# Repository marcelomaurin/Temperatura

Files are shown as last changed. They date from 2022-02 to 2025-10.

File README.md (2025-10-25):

# Projeto Temperatura – Documentação Aprimorada

## Visão Geral

O Projeto Temperatura é uma solução integrada para o controle e monitoramento contínuo de temperatura e umidade em ambientes críticos, como farmácias e geladeiras de medicamentos. O sistema opera 24/7, registrando dados em tempo real e gerando relatórios detalhados com valores atuais, máximos e mínimos, garantindo a segurança e preservação de produtos sensíveis.

## Finalidade

- Monitorar constantemente temperatura e umidade ambiental;
- Assegurar a qualidade e segurança de produtos sensíveis, especialmente medicamentos;
- Gerar relatórios analíticos para acompanhamento e controle eficaz.

## Vantagens

- Operação ininterrupta, 24 horas por dia, 7 dias por semana;
- Relatórios precisos com dados atuais, máximos e mínimos de temperatura e umidade;
- Sistema open source para flexibilidade e personalização;
- Compatível com três tipos de equipamentos de aquisição de dados.

## Equipamentos Suportados

1. **USB Serial (Arduino Nano)**: Comunicação via porta serial USB, ideal para instalações locais simples.  
2. **Ethernet (Arduino Mega com Ethernet Shield)**: Comunicação via rede cabeada, adequado para ambientes com infraestrutura Ethernet.  
3. **ESP8266 (Wi-Fi)**: Conexão sem fio via módulo Wi-Fi, oferecendo maior flexibilidade na instalação.

## Estrutura do Projeto

- **hardware/**: Firmwares para Arduino Nano, Mega com Ethernet Shield e ESP8266, manuais e modelos 3D (STL/SLDPRT) dos dispositivos e protetores.
- **software/**: Código-fonte da aplicação principal em Pascal/Delphi, banco de dados SQLite, instaladores para Windows e Linux, bibliotecas e ferramentas auxiliares (SQLiteStudio).
- **docs/**: Documentação técnica, manuais em PDF.
- **imgs/**: Imagens e capturas de tela ilustrativas de hardware e software.
- **.git/**: Configurações e arquivos para controle de versão com Git.

## Instalação e Configuração

1. Instale o equipamento de medição adequado ao ambiente.  
2. Configure o software informando o tipo do equipamento e parâmetros de comunicação.  
3. Execute a aplicação para iniciar o monitoramento contínuo.

## Interface do Sistema – Exemplos de Telas

### MSTemp01 – Visões dos Sensores  

| Visão Superior | Visão Traseira |
|---|---|
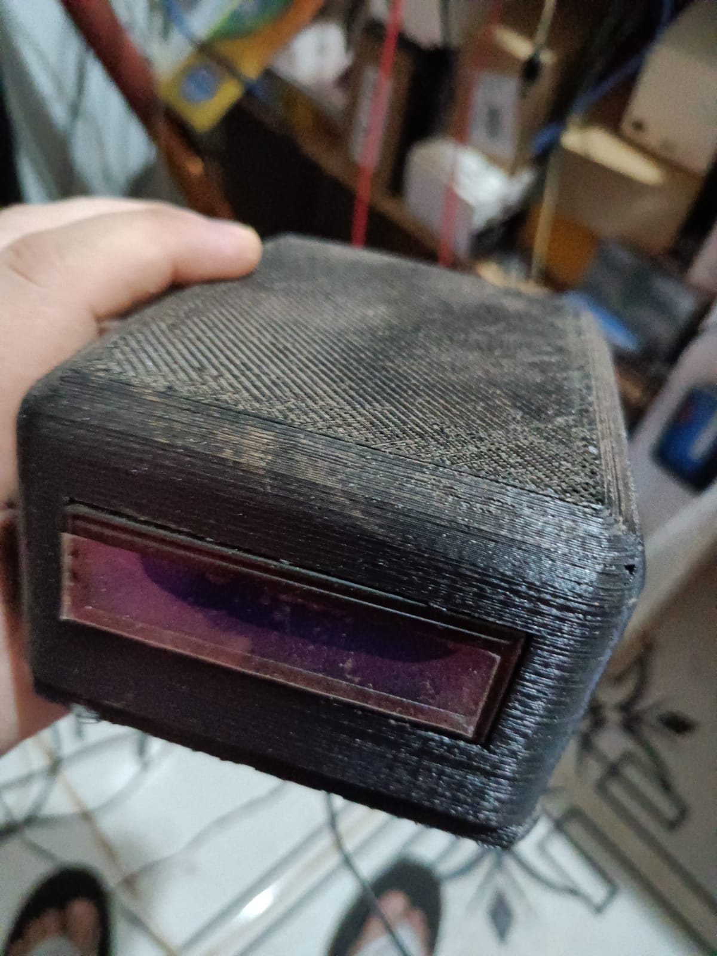
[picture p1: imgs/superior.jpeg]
Visão Superior
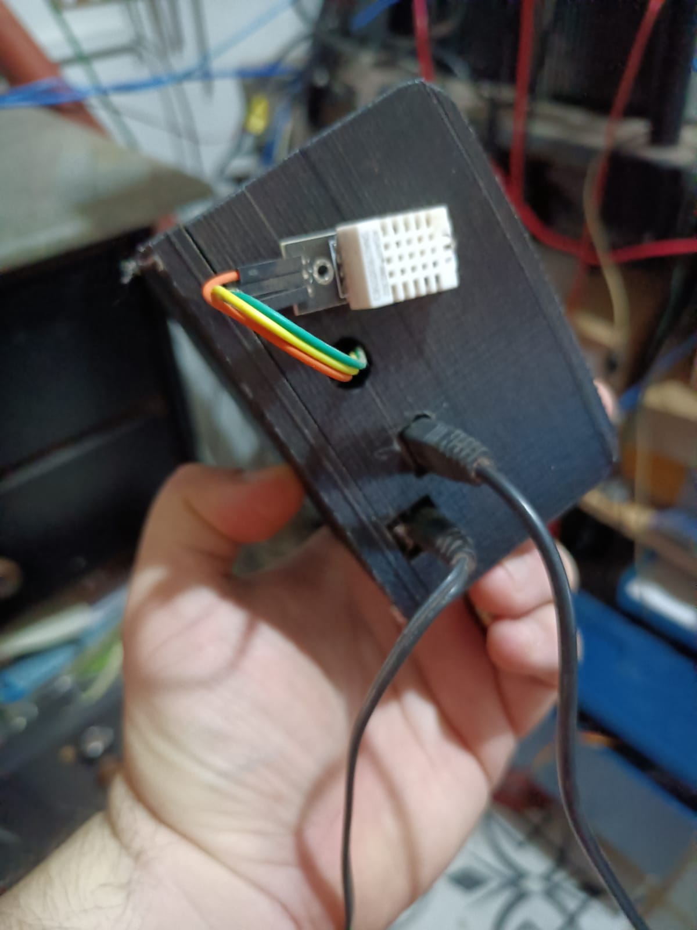
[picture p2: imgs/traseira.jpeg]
Visão Traseira
|  |  |

## Imagens do projeto

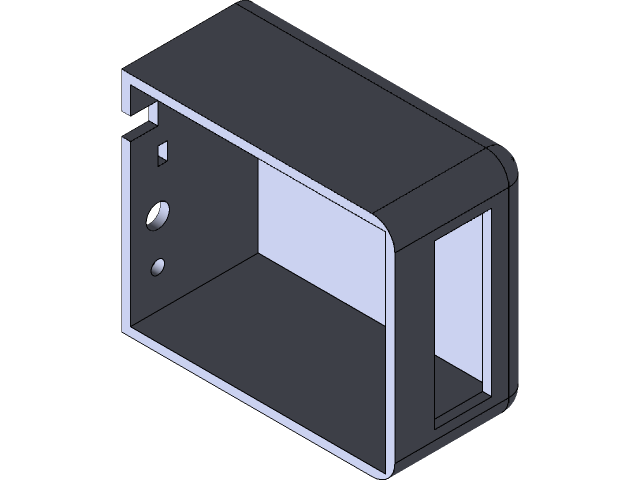
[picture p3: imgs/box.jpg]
|  |
|---------------------|
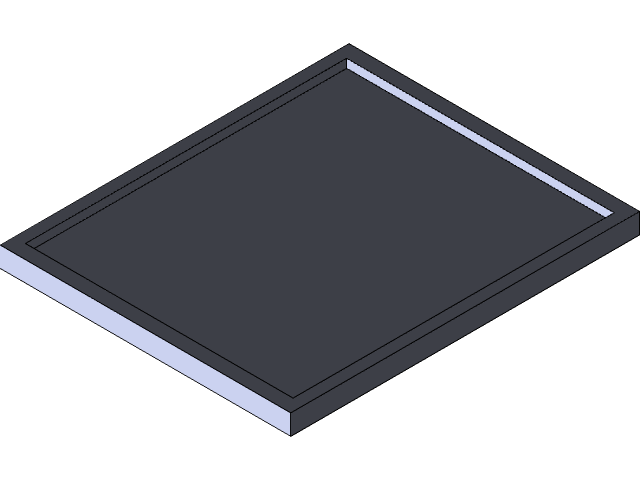
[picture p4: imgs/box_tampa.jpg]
|  |
|  |
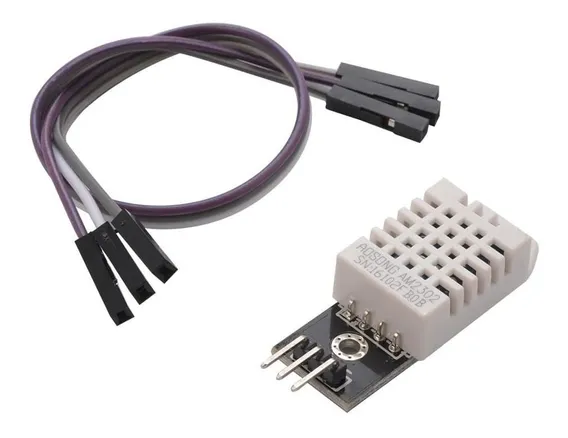
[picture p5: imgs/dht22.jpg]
|  |
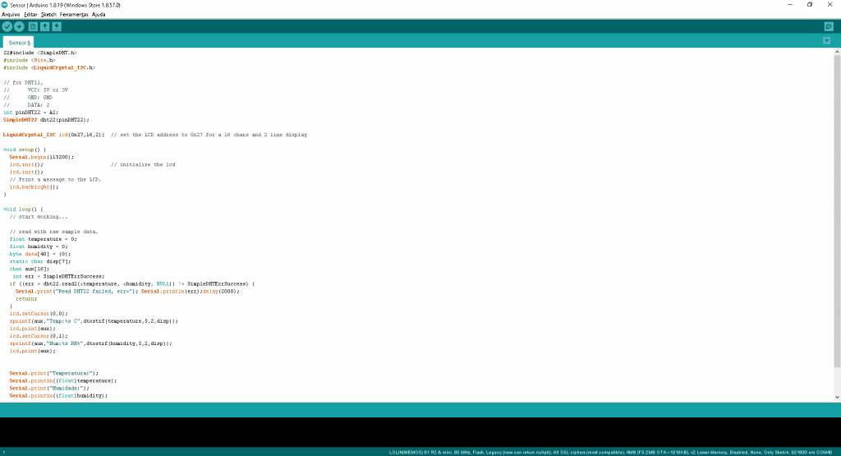
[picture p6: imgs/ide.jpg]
|  |
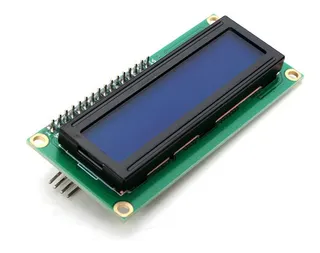
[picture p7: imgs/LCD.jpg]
|  |
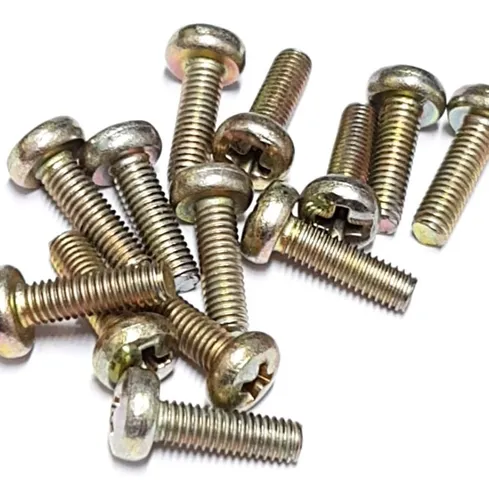
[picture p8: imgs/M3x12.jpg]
|  |
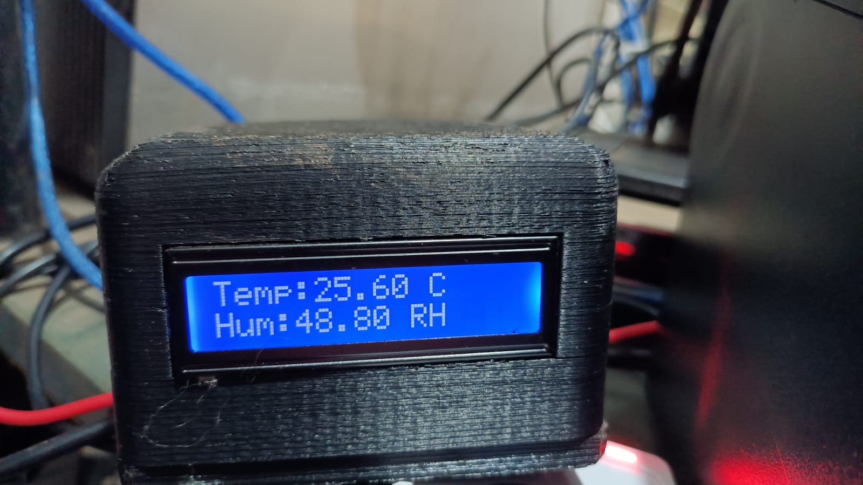
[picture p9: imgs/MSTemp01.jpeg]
|  |
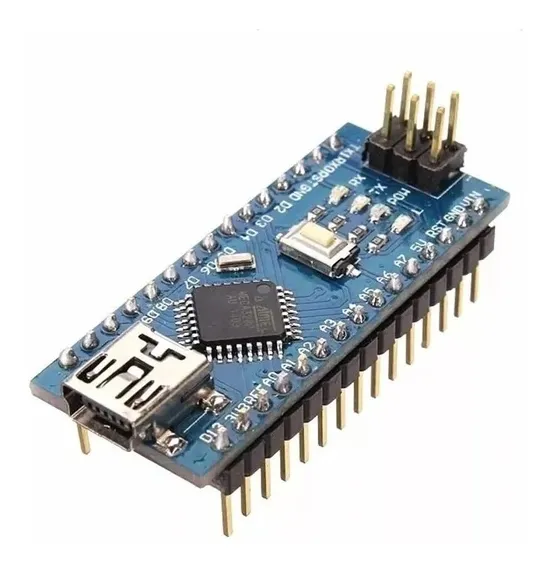
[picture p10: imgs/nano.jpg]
|  |
| setup_protetor_100.exe |
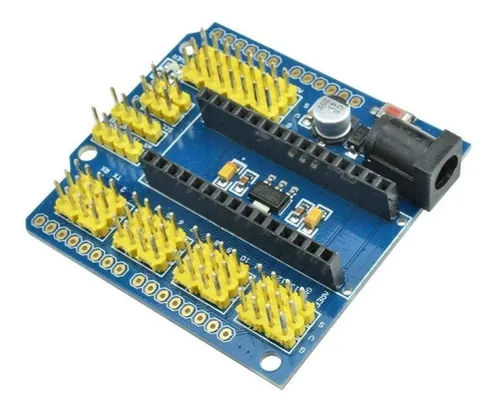
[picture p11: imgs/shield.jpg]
|  |
|  |
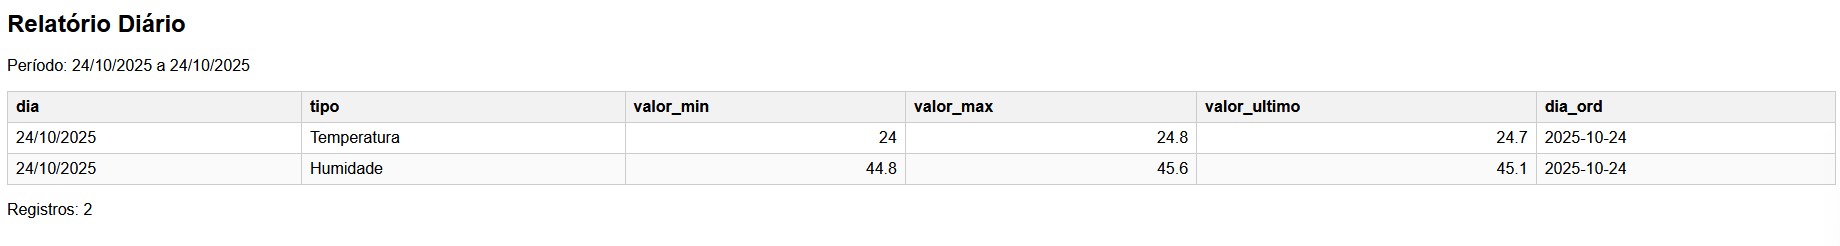
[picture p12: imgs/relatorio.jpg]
|  |
|  |
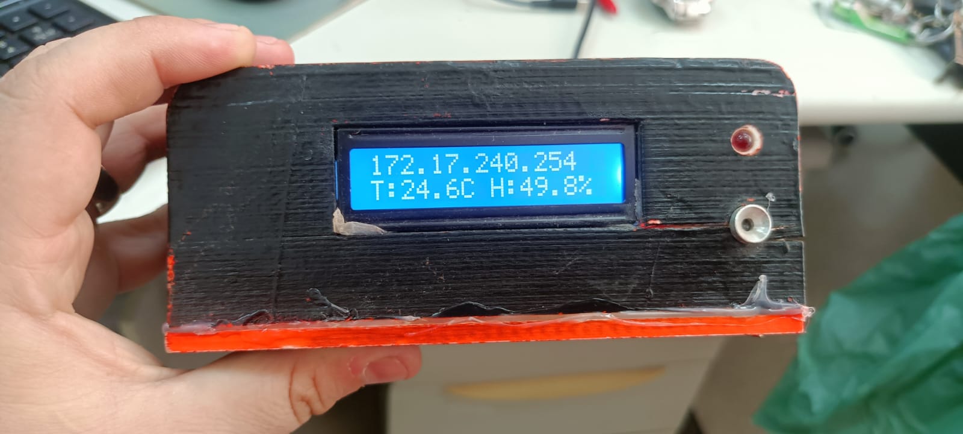
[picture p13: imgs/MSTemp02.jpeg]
|  |
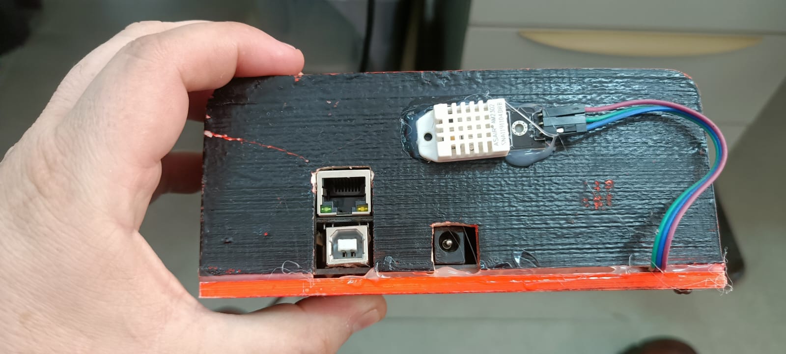
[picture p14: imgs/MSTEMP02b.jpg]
|  |
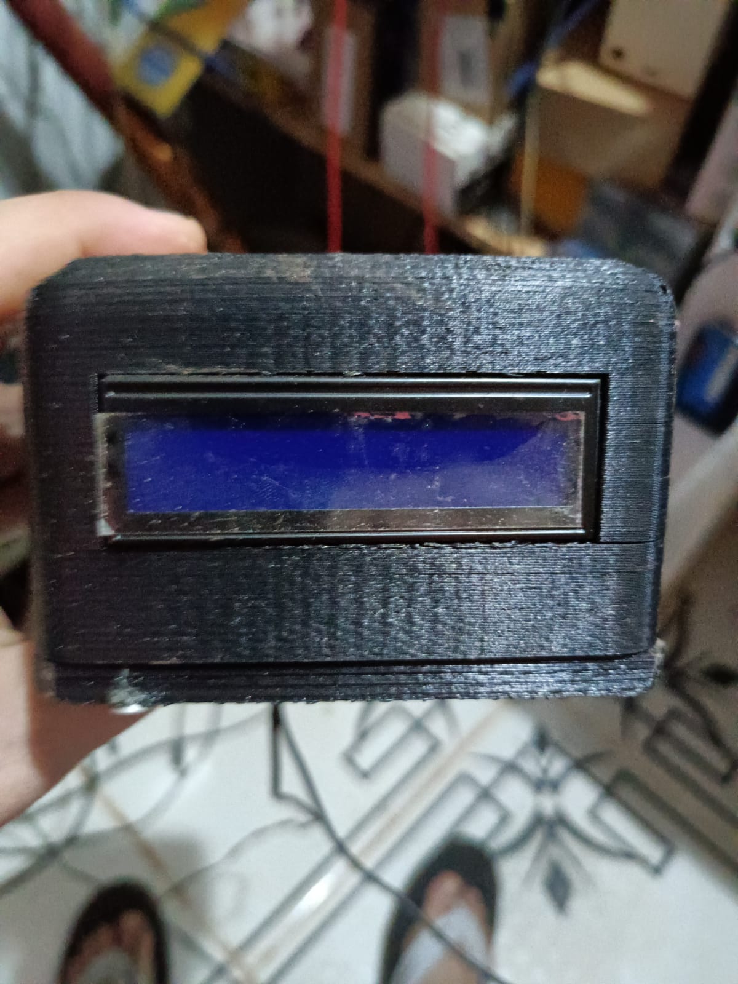
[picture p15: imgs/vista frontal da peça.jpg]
vista frontal da peça.jpg
|  |

## Telas do Instalador

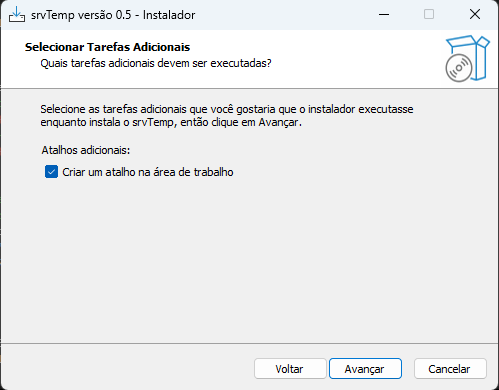
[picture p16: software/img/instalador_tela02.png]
Instalador 2
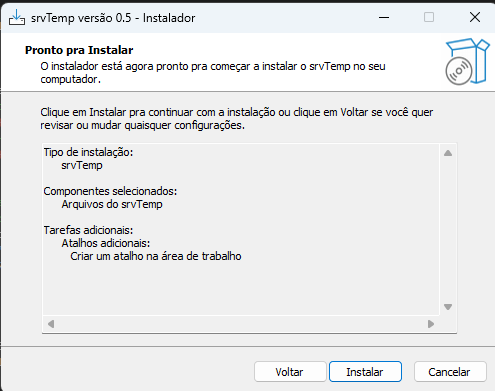
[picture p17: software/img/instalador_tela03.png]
Instalador 3
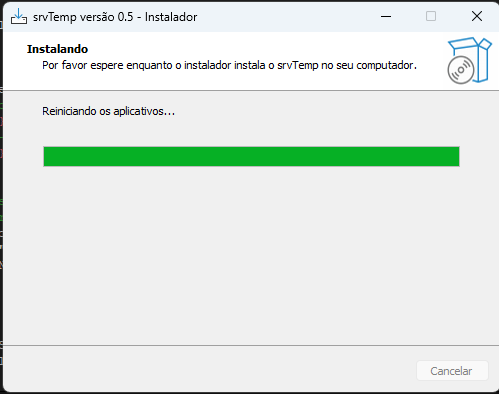
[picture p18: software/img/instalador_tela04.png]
Instalador 4
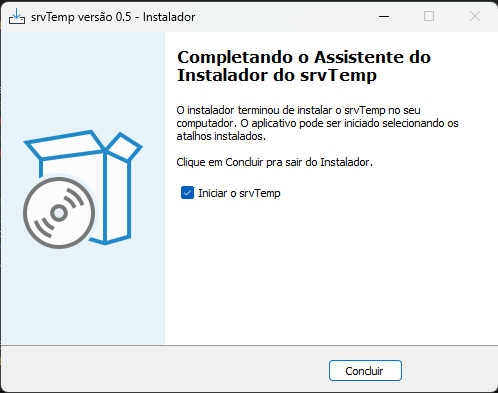
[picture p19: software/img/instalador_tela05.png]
Instalador 5
|  |  |  |  |
|---|---|---|---|

## Projeto de Sensor de Temperatura em Arduino

O projeto suporta leitura e compartilhamento de dados de temperatura e umidade por meio de:  

- Equipamento com Web API para dados de temperatura;  
- Equipamento com Web API para integração com outros sistemas.

Mais informações:  
[https://maurinsoft.com.br/index.php/sensor-de-temperatura/](https://maurinsoft.com.br/index.php/sensor-de-temperatura/)

## Licença

Uso livre para pessoas físicas e jurídicas para uso próprio. Proibida montagem para venda. Firmware e software são open source, porém alterações no código original não autorizadas.

## Customizações

Solicitações de customização podem ser enviadas via contato:  
[https://maurinsoft.com.br/index.php/fale-conosco/](https://maurinsoft.com.br/index.php/fale-conosco/)

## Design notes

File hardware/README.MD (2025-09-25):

# Equipamentos

O projeto possui firmware para diversos equipamentos.

- Leitura Serial - MSTemp01
- Rede Ethernet - MSTemp02
- Wifi - Esp12E/Temperatura

# Atenção
Cada equipamento possui caracteristicas especificas.
Consulte a documentação do projeto.

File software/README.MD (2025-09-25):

# Software de Gestão de Temperatura

# Hardware Requerido
Este equipamento foi testado em Windows 11. 

- 4Gb de RAM
- 10Gb de Disco livre

# Funcionalidades
O software permite leitura de dispositivos serial ou ethernet.

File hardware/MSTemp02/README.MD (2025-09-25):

# 🌡️ Monitor de Temperatura & Umidade  
**Plataforma:** Arduino Mega 2560 + Ethernet Shield + DHT22  

Sistema embarcado para leitura de temperatura/umidade, interface web responsiva e registro em SD.

---

## ✨ Funcionalidades
- 📊 Leitura de temperatura/umidade (DHT22).
- 🖥️ Exibição em LCD I²C 16×2.
- 🌐 Servidor web na porta `8081` com Bootstrap.
- 🗄️ Registro histórico em cartão SD (`LYYYYMM.CSV`).
- ⏰ Sincronização NTP (UTC) a cada 10 min.
- ⚙️ Configuração de rede persistente na EEPROM (DHCP ou estático).
- 🔧 Calibração direta ou de 2 pontos (ganho + offset).
- 🔔 Alarme sonoro ao cruzar 30 °C.

---

## 🔌 Hardware
- **Placa:** Arduino Mega 2560  
- **Shield:** Ethernet (W5100/W5500) + SD no mesmo barramento SPI  
- **Sensores:**
  - DHT22 em D6
  - LCD I²C (0x27)
- **Outros:**
  - Buzzer (A11) + enable (A8)
  - LED status (D7)

---

## 📚 Bibliotecas
- `DHT.h`
- `LiquidCrystal_I2C.h`
- `Ethernet.h`, `EthernetUdp.h`
- `Dns.h`, `SPI.h`
- `EEPROM.h`
- `SdFat.h` (v2+)

---

## 🌐 Rede e EEPROM
- **DHCP** ou IP estático (`172.17.240.253` padrão).
- Configurações persistentes em EEPROM:
  - `use_static`, `ip`, `dns`, `gw`, `mask`, `mac`
  - `kTemp`, `aTemp`, `kHum`, `aHum`
- `magic` (0x42) e `checksum` para validar dados.

---

## 🗂️ Registro no SD
- Arquivos por mês: `LYYYYMM.CSV`
- Cabeçalho: `epoch,temperature,humidity`
- Só grava se ΔT ≥ 1 °C ou ΔH ≥ 1 %

---

## 🌍 Interface Web
### Páginas
- `/` – Status e configuração de rede
- `/historico` – Gráficos (Chart.js)
- `/export` – Download e limpeza de CSV
- `/calibracao` – Ajuste de k/offset ou modo 2 pontos

### APIs
```http
GET /ws/temperatura      # JSON atual
GET /ws/log?hours=24     # Últimas 24h
GET /ws/log?yyyymm=202509
GET /ws/csv?yyyymm=202509
GET /ws/clear?yyyymm=202509
GET /ws/calib?kt=1&at=0&kh=1&ah=0
```

# 🏗️ Fluxo de Boot

## Configura pinos e periféricos.

- Lê EEPROM (ou aplica defaults).

- Conecta rede (DHCP/estático).

- Sincroniza NTP.

- Inicializa SD.

- Exibe IP no LCD.

Loop principal: leitura DHT, gravação condicional, HTTP.

## 🛠️ Compilação

IDE: Arduino IDE

Placa: Arduino Mega 2560

Serial: 115200 baud

## 🧪 Testes Rápidos
### JSON atual
curl http://<IP>:8081/ws/temperatura

### Log mês 2025-09
curl http://<IP>:8081/ws/log?yyyymm=202509

### Exportar CSV
curl -OJ http://<IP>:8081/ws/csv?yyyymm=202509

## 📜 Licença

Open Source - Livre uso e montagem, sem cobrança para este fim.
Proibido a venda por terceiros sem autorização prévia. 
Proibido a customização ou modificação.
Proibido a incorporação.

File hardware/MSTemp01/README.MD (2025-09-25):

# Leitura de Temperatura e Umidade com DHT22 + LCD I²C (Arduino)

Projeto simples para ler temperatura e umidade usando um DHT22 e exibir os valores em um LCD 16x2 via I²C. 

Também envia os dados pela Serial (115200).

Este equipamento é criado para monitorar via USB/Serial.

Observação importante: o código usa a classe SimpleDHT22 (sensor DHT22). 
O hardware e a classe utilizados são DHT22.

## 🧩 Hardware

- Arduino (Uno/Nano/MEGA — 5V ou 3.3V)
- Sensor DHT22
- LCD 16x2 I²C (endereços comuns: 0x27 ou 0x3F)
(Recomendado) Resistor de pull-up 10k entre DATA e VCC do DHT22
- Jumpers
- Ligações
- DHT22
- VCC → 5V (ou 3.3V)
- GND → GND
- DATA → A2 (conforme o código)
- LCD I²C (PCF8574)
- VCC → 5V
- GND → GND
- SDA → A4 (Arduino Uno/Nano)
- SCL → A5 (Arduino Uno/Nano)

Em placas diferentes, confira os pinos SDA/SCL (ex.: MEGA: SDA=20, SCL=21).

## 📦 Bibliotecas

Instale pela IDE do Arduino (Gerenciador de Bibliotecas) ou via ZIP:

SimpleDHT (para DHT22)

LiquidCrystal_I2C (LCD I²C)

Wire (já vem na IDE)

## 🔧 Configuração no Código
- int pinDHT22 = A2;                 // Pino DATA do DHT22
- SimpleDHT22 dht22(pinDHT22);
- LiquidCrystal_I2C lcd(0x27,16,2);  // Endereço I²C do LCD e dimensões

Se o LCD não aparecer, teste o endereço 0x3F.

Para outro pino do sensor, altere pinDHT22.

## ▶️ Como usar

Conecte o hardware conforme descrito.

Abra a IDE do Arduino → selecione a placa/porta correta.

Instale as bibliotecas.

Cole o código do seu sketch.

Faça o Upload.

Abra o Monitor Serial em 115200 baud.

## 🖥️ O que aparece

### No LCD

Linha 1: Temp:XX.XX C

Linha 2: Hum:YY.YY RH

### Na Serial

Temperatura:25.37
Humidade:58.42

(A leitura é atualizada a cada ~1,5 s.)

## 🛡️ Boas práticas

Use pull-up 10k no DATA do DHT22 para leituras estáveis.

Evite cabos longos no sensor (ou use cabo blindado).

Alimente o sensor com tensão estável (3.3V ou 5V).

DHT22 tem taxa de amostragem ~0,5–1 Hz (respeite delay(1500)).

🧪 Troubleshooting

LCD sem texto: verifique o endereço (0x27 ↔ 0x3F) e o contraste (trimpot da placa I²C).

Leitura falhou (Read DHT22 failed): confira cabos, pull-up e alimentação.

Valores “nan”/zero: verifique o pino DATA e o aterramento comum (GND único).

## 🗂️ Estrutura do Sketch

setup(): inicia Serial e LCD, liga backlight.

loop(): lê DHT22 (read2), formata e mostra no LCD, imprime na Serial, aguarda 1500 ms.

## 🔁 Personalizações rápidas

Mudar pino do DHT22: int pinDHT22 = A2; → A1/D2/...

Mudar endereço do LCD: LiquidCrystal_I2C lcd(0x27,16,2); → 0x3F

Ajustar intervalo de leitura: delay(1500); (evite < 1000 ms para DHT22)

## 📜 Licença

Open Source - Livre uso e montagem, sem cobrança para este fim.
Proibido a venda por terceiros sem autorização prévia. 
Proibido a customização ou modificação.
Proibido a incorporação.

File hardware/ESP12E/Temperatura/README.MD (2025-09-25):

# MSTemp02
📘 Documentação – ESP8266 WiFi Setup + DHT11 + mDNS (srvTemp)
📖 Visão Geral

Este projeto implementa uma solução completa para configuração de Wi-Fi e monitoramento de temperatura/umidade usando um ESP8266 (NodeMCU/Lolin/ESP-12E).

Quando energizado, o dispositivo:

Tenta conectar ao último Wi-Fi salvo na EEPROM.

Se não encontrar ou falhar, cria uma rede Wi-Fi AP chamada srvTemp.

Disponibiliza uma página web (estilo D-Link, responsiva com Bootstrap) para seleção de SSID, senha e visualização de sensores.

Salva as credenciais na EEPROM, tenta se conectar à rede escolhida e reinicia o servidor web.

Disponibiliza API REST para status, redes disponíveis e leitura de sensores.

Responde sempre com a página principal em qualquer rota chamada na porta 80 (catch-all).

## 🛠️ Hardware Necessário

Placa ESP8266 (NodeMCU/Lolin/ESP-12E).

Sensor DHT11 conectado ao GPIO4 (D2):

- VCC → 3.3V
- DATA → D2 (com resistor pull-up de 10k para 3.3V)
- GND → GND

## 📦 Bibliotecas Utilizadas

- ESP8266WiFi
- ESP8266WebServer
- DNSServer
- EEPROM
- DHT Sensor Library
- ESP8266mDNS

## 🌐 Funcionalidades
Portal Cativo

Cria rede srvTemp (AP).

Redireciona qualquer endereço para a página de configuração.

Responsivo com Bootstrap 5 e visual clean, similar a roteadores D-Link.

Configuração Wi-Fi

Busca redes disponíveis (/scan).

Permite salvar SSID e senha na EEPROM.

Após salvar, tenta se conectar à rede automaticamente.

Leitura de Sensores

Lê temperatura e umidade via DHT11 a cada 3 segundos.

Exibe valores em tempo real na página principal.

Disponibiliza API REST para integração:
´´´
Endpoint /dht
{
  "temp": 26.3,
  "hum": 52.0,
  "ts": 123456
}
´´´

## mDNS

Disponível em http://srvtemp.local (quando conectado na mesma rede).

Publica serviço http._tcp para descoberta automática.

Catch-All na Porta 80

Qualquer endereço acessado retorna a página principal, ideal para experiência de portal cativo.

## 🔗 Endpoints HTTP
Endpoint	Método	Descrição
- /	GET	Página principal (menu HTML).
- /status	GET	Retorna JSON com modo de operação (AP/STA), IP, SSID e RSSI.
- /scan	GET	Varre redes Wi-Fi próximas e retorna JSON com SSID, canal, RSSI e tipo.
- /save	POST	Recebe SSID e senha via x-www-form-urlencoded, salva na EEPROM e tenta conectar.
- /clear	POST	Limpa credenciais salvas e reinicia AP.
- /dht	GET	Retorna leitura de temperatura e umidade.

## 🖼️ Interface Web

Responsiva (mobile-first).

Estilo D-Link simplificado.

Exibe status de rede e dados de sensores.

Botões para buscar redes, salvar credenciais e limpar EEPROM.

## 🧪 Fluxo de Uso

Primeiro uso: conecte no Wi-Fi srvTemp.

Abra o navegador e acesse http://192.168.4.1/.

Clique em Buscar redes, selecione o SSID, informe a senha e clique em Salvar e Conectar.

O dispositivo tenta conectar e, se bem-sucedido, passa a responder em http://srvtemp.local.

Acesse /dht ou visualize a leitura na própria página inicial.

## 🐞 Depuração

No setup(), é exibido no Serial:

Razão do último reset via ESP.getResetReason().

Logs de conexão Wi-Fi.

Logs de POST /save e valores recebidos.

## 📜 Licença

Open Source - Livre uso e montagem, sem cobrança para este fim.
Proibido a venda por terceiros sem autorização prévia. 
Proibido a customização ou modificação.
Proibido a incorporação.

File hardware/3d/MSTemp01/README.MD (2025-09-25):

## Modelos de Peças 3D 

Peças para impressão da Caixa do Projeto MSTemp01

Estes modelos não servem para demais equipamentos.

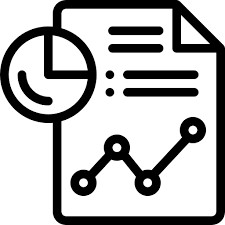
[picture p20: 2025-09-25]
imgs/report.png

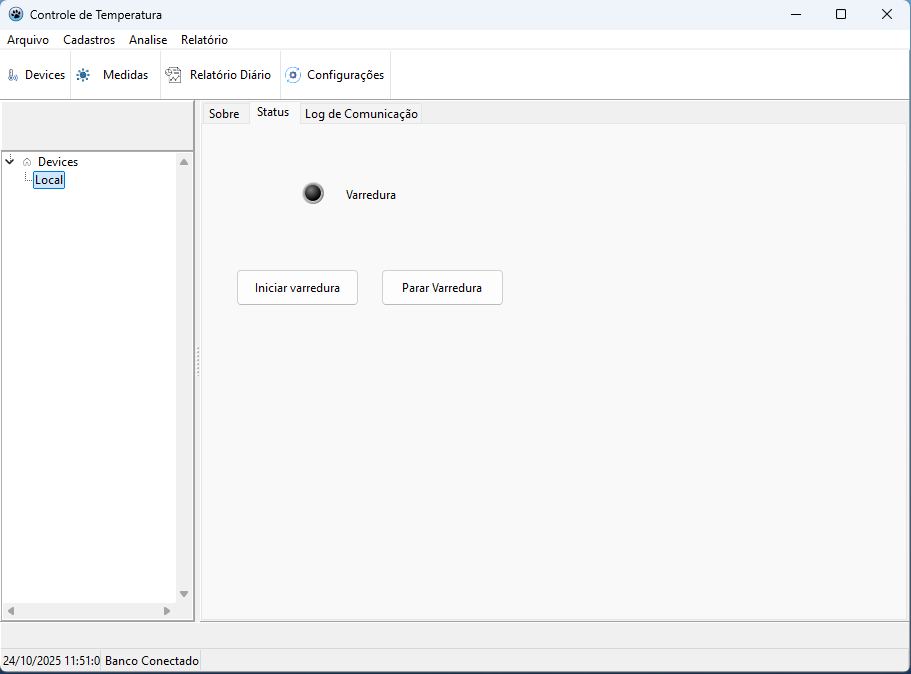
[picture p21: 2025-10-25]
software/img/startdevices.png

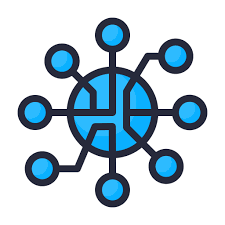
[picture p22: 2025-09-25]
imgs/medidas.png

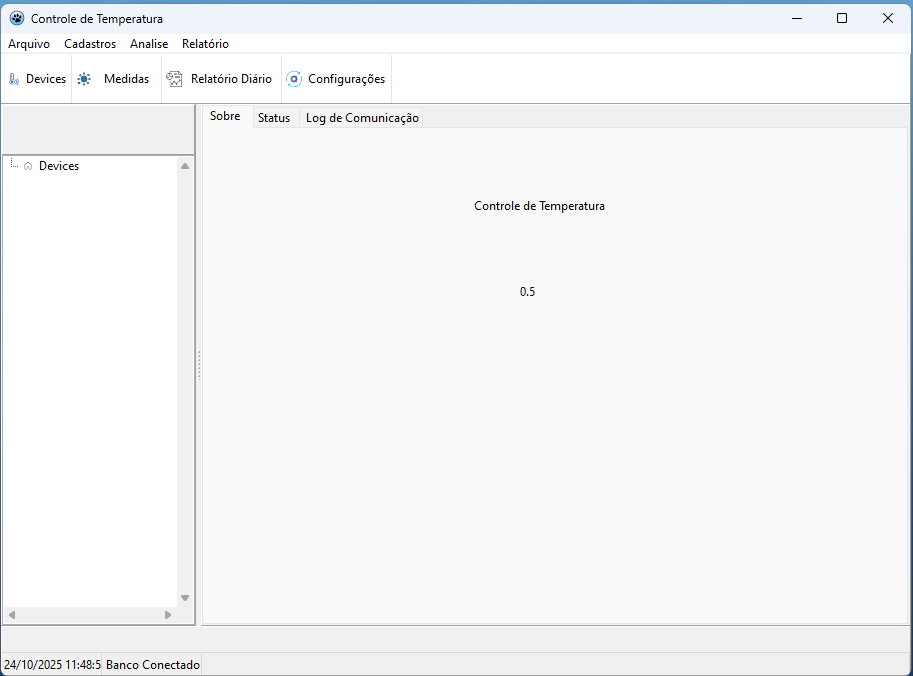
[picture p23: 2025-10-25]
software/img/main.png

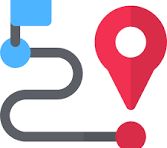
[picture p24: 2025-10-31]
imgs/route.png

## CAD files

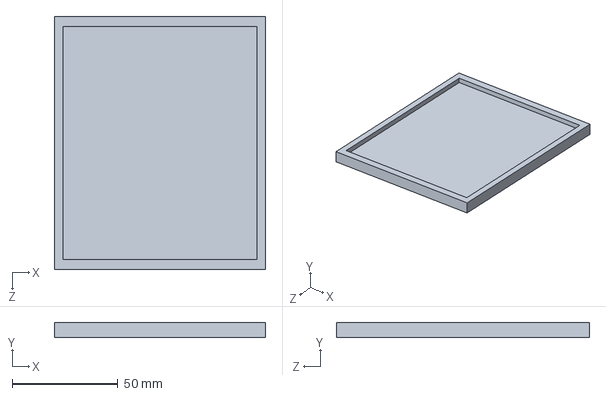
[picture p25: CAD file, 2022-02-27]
hardware/3d/MSTemp01/tampa.SLDPRT
100.0 x 7.00 x 120.0 mm

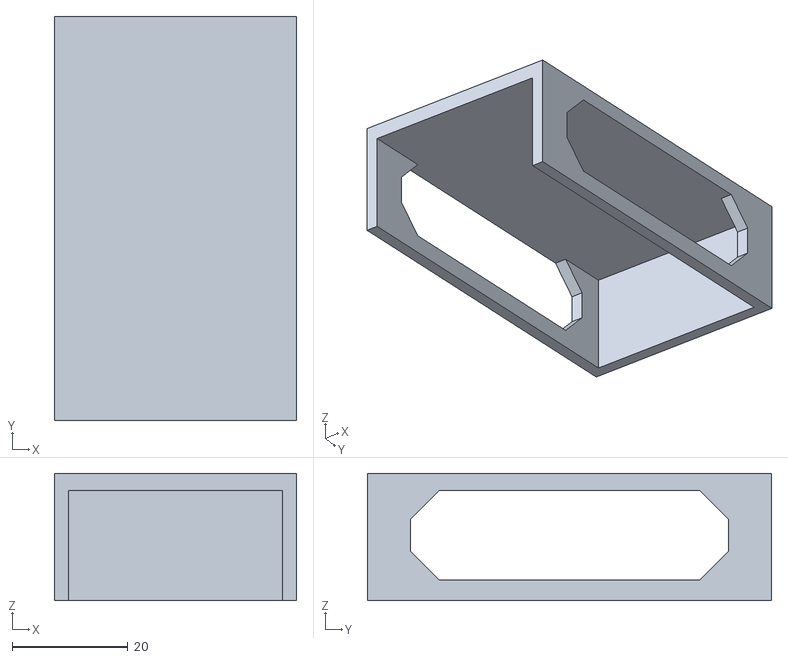
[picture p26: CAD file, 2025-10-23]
hardware/stl/Lolin_DHT_LID_0_1.stl
41.8 x 69.8 x 22.0

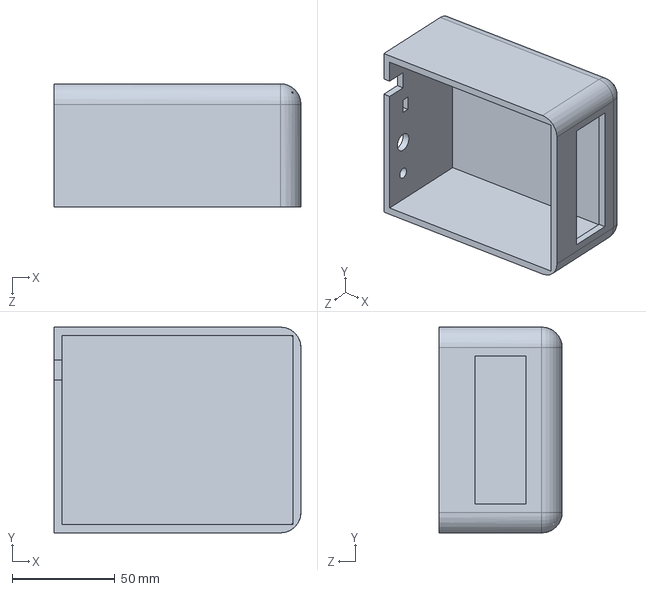
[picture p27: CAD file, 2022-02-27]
hardware/3d/MSTemp01/mostrador.SLDPRT
120.0 x 100.0 x 60.0 mm

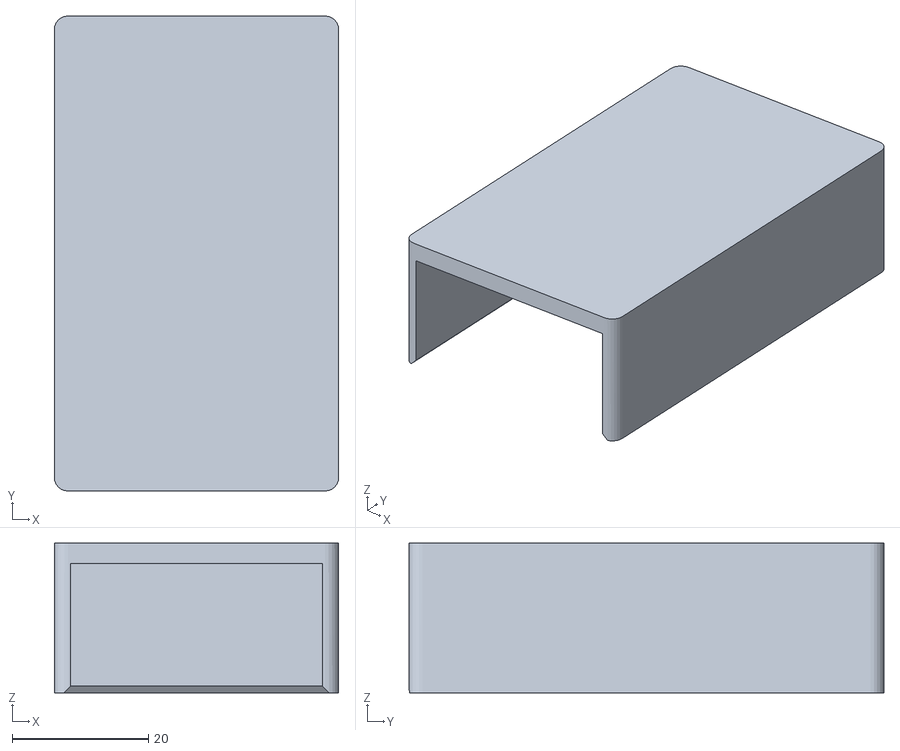
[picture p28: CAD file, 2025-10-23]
hardware/stl/Lolin_DHT_LID_0_2.stl
41.8 x 69.8 x 22.0

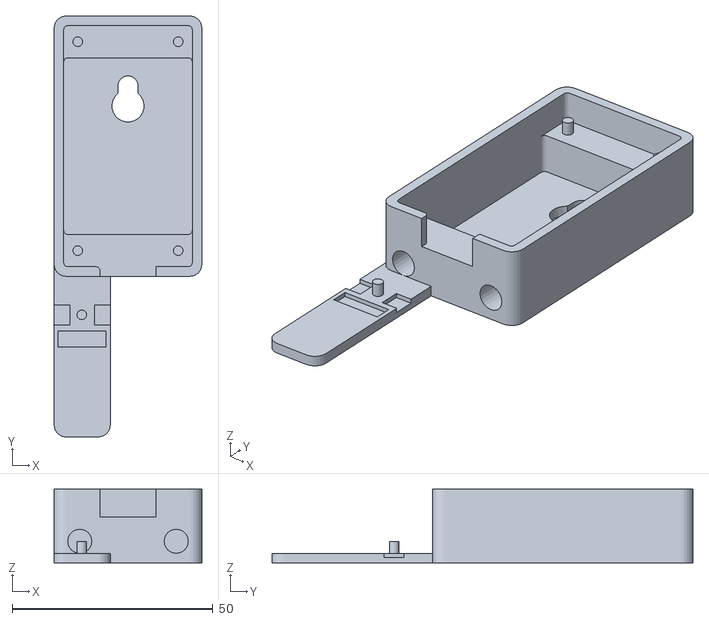
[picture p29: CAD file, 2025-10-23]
hardware/stl/Lolin_DHT_housing_0_3.stl
36.8 x 104.8 x 18.4

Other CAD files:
hardware/stl/MSTemp01/mostrador.STL
hardware/stl/MSTemp01/tampa.STL

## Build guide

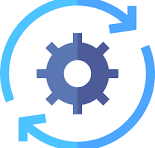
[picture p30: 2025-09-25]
imgs/setup.png

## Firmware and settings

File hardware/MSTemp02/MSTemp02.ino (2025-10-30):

/*
  Firmware "mega temp02" - Monitor T/H c/ LCD, SD, HTTP, NTP
  Serial Verbose: imprime tudo que importa pra diagnosticar.

  ► Principais endpoints:
    /                 -> Dashboard (status/rede)
    /historico        -> Gráficos (Chart.js) por mês
    /export           -> Download CSV (por mês) e limpar arquivo do mês
    /ws/temperatura   -> JSON com leitura atual
    /ws/log           -> JSON histórico (param: yyyymm=YYYYMM | hours=24)
    /ws/csv           -> DOWNLOAD CSV (param: yyyymm=YYYYMM) [se usar handleCsvDownload]
    /ws/clear         -> Remove CSV do mês (param: yyyymm=YYYYMM)
    /calibracao       -> Página de calibração (direta e 2 pontos)
    /ws/calib         -> API calibração

  ► Logs na Serial (115200) com prefixos:
    [CFG], [NET], [NTP], [SD], [HTTP], [LOG], [DHT], [CAL], [LCD]
*/

#define SERIAL_VERBOSE 1


#include <Wire.h>
#include <SPI.h>
#include <Ethernet.h>
#include <EEPROM.h>
#include <EthernetUdp.h>
#include <Dns.h>
#include <math.h>
#include <LiquidCrystal_I2C.h>
#include <DHT.h>
#include <SdFat.h>

SdFat    SD;
SdCard   g_sdCard;
FsVolume g_sdVol;

// ======== DEFAULTS (EEPROM ausente) ========
#define DEFAULT_USE_STATIC_IP  0
const IPAddress DEFAULT_IP   (172, 17, 240, 254);
const IPAddress DEFAULT_DNS  (172, 17, 240,   2);
const IPAddress DEFAULT_GW   (172, 17, 240,   1);
const IPAddress DEFAULT_MASK (255, 255, 252,  0);
//const uint8_t  DEFAULT_MAC[6] = {0xDE,0xAD,0xBE,0xEF,0xFE,0xED};
const uint8_t  DEFAULT_MAC[6] = {0x5C,0xCF,0x7F,0x84,0x56,0x56};

// ======== DHCP robusto ========
const uint8_t      DHCP_RETRIES          = 3;      // quantas tentativas de DHCP
const unsigned long DHCP_WAIT_LINK_MS    = 8000;   // espera por link antes do DHCP
const unsigned long DHCP_RETRY_DELAY_MS  = 2000;   // pausa entre tentativas


// ======== Pinos ========
#define DHTPIN 6
#define DHTTYPE DHT22
const int PIN_BUZZER  = A11;
const int PIN_BUZZ_G  = A8;
const int PIN_LED     = 7;
const int PIN_CS_ETH  = 10;
const int PIN_CS_SD   = 4;

// ======== Objetos ========
DHT dht(DHTPIN, DHTTYPE);
LiquidCrystal_I2C lcd(0x27, 16, 2);
EthernetServer server(80);
EthernetUDP Udp;

// ======== NTP ========
const char* NTP_SERVER = "a.st1.ntp.br";
const unsigned int NTP_LOCAL_PORT = 8888;
const unsigned long NTP_INTERVAL_MS = 10UL * 60UL * 1000UL;
unsigned long lastNtpSyncMs = 0;
unsigned long epochAtLastSync = 0;  // UTC
unsigned long msAtLastSync = 0;

// ======== Amostragem ========
unsigned long lastSampleMs = 0;
const unsigned long sampleIntervalMs = 2500;
unsigned long dhtWarmupUntil = 0;
float lastTemp = NAN, lastHum = NAN;

// ======== Alertas ========
const float THRESH_C = 30.0;
bool wasBelowThreshold = true;

// ======== LCD ========
unsigned long ipSplashStartMs = 0;
bool ipSplashDone = false;
const unsigned long IP_SPLASH_MS = 2000;

// ======== SD / Log ========
bool sdAvailable = false;
char currentMonthFile[20] = {0}; // "L202509.CSV"
volatile bool sdBusy = false;
float lastLoggedTemp = NAN;
float lastLoggedHum  = NAN;

// ======== Config persistente (EEPROM) ========
struct NetConfig {
  uint8_t  magic;       // 0x42
  uint8_t  use_static;  // 0/1
  uint8_t  ip[4];
  uint8_t  dns[4];
  uint8_t  gw[4];
  uint8_t  mask[4];
  uint8_t  mac[6];
  // Calibração: y_cal = k * y_raw + a
  float    kTemp; float aTemp;
  float    kHum;  float aHum;
  uint8_t  checksum; // soma simples
};
const uint8_t CFG_MAGIC = 0x42;
const int EEPROM_ADDR = 0;
NetConfig cfg;

void streamCsvAsJson(EthernetClient &client,
                     unsigned long minEpoch,
                     unsigned long maxEpoch,
                     int yearMonth,
                     bool debugLogs = false);


// ======== Helpers ========
static inline float applyCalTemp(float raw){ return isnan(raw) ? raw : (cfg.kTemp*raw + cfg.aTemp); }
static inline float applyCalHum (float raw){ return isnan(raw) ? raw : (cfg.kHum *raw + cfg.aHum ); }

static inline void macToString(const uint8_t mac[6], char* buf, size_t sz){
  snprintf(buf, sz, "%02X:%02X:%02X:%02X:%02X:%02X",
    mac[0],mac[1],mac[2],mac[3],mac[4],mac[5]);
}

static inline String ipToString(IPAddress ip){
  char s[24]; snprintf(s,sizeof(s),"%u.%u.%u.%u",ip[0],ip[1],ip[2],ip[3]); return String(s);
}

uint8_t calcChecksum(const NetConfig &c){
  const uint8_t *p = (const uint8_t*)&c;
  uint16_t s=0;
  for(size_t i=0;i<sizeof(NetConfig)-1;i++) s+=p[i];
  return (uint8_t)(s & 0xFF);
}

// Itera linhas do CSV e envia JSON filtrado.
// minEpoch/maxEpoch: filtro por epoch (0 = sem filtro no lado).
// yearMonth: yyyymm para ler exatamente LYYYYMM.CSV; se -1, tenta mês atual e anterior.
// debugLogs: imprime métricas no Serial.
void streamCsvAsJson(EthernetClient &client,
                     unsigned long minEpoch,
                     unsigned long maxEpoch,
                     int yearMonth,
                     bool debugLogs) {
  unsigned long t0 = millis();
  if (!sdAvailable) { client.println(F("[]")); return; }

  // ---- SPI handoff: desabilita Ethernet p/ operar SD ----
  digitalWrite(PIN_CS_ETH, HIGH);

  bool first = true;
  client.print('[');

  // Métricas de debug
  unsigned long filesTried = 0, filesOpened = 0;
  unsigned long linesTotal = 0, linesParsed = 0, linesEmitted = 0;

  auto streamFile = [&](const char* fname){
    if (!SD.exists(fname)) {
      if (debugLogs) { Serial.print(F("[WS/LOG] arquivo inexistente: ")); Serial.println(fname); }
      return;
    }
    filesTried++;
    File f = SD.open(fname, FILE_READ);
    if (!f) {
      if (debugLogs) { Serial.print(F("[WS/LOG] falha ao abrir: ")); Serial.println(fname); }
      return;
    }
    filesOpened++;

    String line;
    while (f.available()) {
      char c = f.read();
      if (c=='\n' || c=='\r') {
        if (line.length()>0) {
          linesTotal++;
          if (!line.startsWith(F("epoch,"))) {
            int p1 = line.indexOf(',');
            int p2 = line.indexOf(',', p1+1);
            if (p1>0 && p2>p1) {
              unsigned long e = (unsigned long) line.substring(0,p1).toInt();
              if (e != 0 && (minEpoch==0 || e>=minEpoch) && (maxEpoch==0 || e<=maxEpoch)) {
                String st = line.substring(p1+1, p2);
                String sh = line.substring(p2+1);
                if (!first) client.print(',');
                client.print(F("{\"epoch\":")); client.print(e);
                client.print(F(",\"temperature\": ")); client.print(st);
                client.print(F(",\"humidity\": ")); client.print(sh);
                client.print('}');
                first=false;
                linesEmitted++;
              }
              linesParsed++;
            }
          }
        }
        line = "";
      } else {
        line += c;
      }
    }
    f.close();
  };

  if (yearMonth > 0) {
    char fname[20];
    formatMonthFilenameFromYYYYMM((uint32_t)yearMonth, fname, sizeof(fname));
    if (debugLogs) { Serial.print(F("[WS/LOG] modo yyyymm, arquivo=")); Serial.println(fname); }
    streamFile(fname);
  } else {
    // Lê mês atual + anterior
    unsigned long nowEpoch = getEpochUTC();
    updateMonthFileName(nowEpoch);
    char cur[20]; strncpy(cur, currentMonthFile, sizeof(cur)); cur[sizeof(cur)-1] = '\0';

    unsigned long prevEpoch = (nowEpoch > 31UL*86400UL) ? (nowEpoch - 31UL*86400UL) : 0UL;
    updateMonthFileName(prevEpoch);
    char prev[20]; strncpy(prev, currentMonthFile, sizeof(prev)); prev[sizeof(prev)-1] = '\0';

    // restaura nome do mês atual
    updateMonthFileName(nowEpoch);

    if (debugLogs) {
      Serial.print(F("[WS/LOG] lendo prev=")); Serial.print(prev);
      Serial.print(F(" cur=")); Serial.println(cur);
      Serial.print(F("[WS/LOG] filtro minEpoch=")); Serial.print(minEpoch);
      Serial.print(F(" maxEpoch=")); Serial.println(maxEpoch);
    }

    streamFile(prev);
    streamFile(cur);
  }

  client.println(']');

  // ---- solta o SD ----
  digitalWrite(PIN_CS_SD, HIGH);

  if (debugLogs) {
    Serial.print(F("[WS/LOG] filesTried="));  Serial.print(filesTried);
    Serial.print(F(" opened="));              Serial.print(filesOpened);
    Serial.print(F(" linesTotal="));          Serial.print(linesTotal);
    Serial.print(F(" linesParsed="));         Serial.print(linesParsed);
    Serial.print(F(" linesEmitted="));        Serial.print(linesEmitted);
    Serial.print(F(" ms="));                  Serial.println(millis()-t0);
  }
}


void loadDefaults(NetConfig &c){
  c.magic = CFG_MAGIC;
  c.use_static = DEFAULT_USE_STATIC_IP ? 1 : 0;
  for(int i=0;i<4;i++){
    c.ip[i]=DEFAULT_IP[i]; c.dns[i]=DEFAULT_DNS[i];
    c.gw[i]=DEFAULT_GW[i]; c.mask[i]=DEFAULT_MASK[i];
  }
  for(int i=0;i<6;i++) c.mac[i]=DEFAULT_MAC[i];
  c.kTemp=1.0f; c.aTemp=0.0f;
  c.kHum =1.0f; c.aHum =0.0f;
  c.checksum = calcChecksum(c);
}

bool loadConfig(NetConfig &c){
  EEPROM.get(EEPROM_ADDR, c);
  if(c.magic!=CFG_MAGIC) return false;
  if(c.checksum!=calcChecksum(c)) return false;
  if (!isfinite(c.kTemp)) c.kTemp=1.0f;
  if (!isfinite(c.aTemp)) c.aTemp=0.0f;
  if (!isfinite(c.kHum )) c.kHum =1.0f;
  if (!isfinite(c.aHum )) c.aHum =0.0f;
  return true;
}
void saveConfig(const NetConfig &c){ EEPROM.put(EEPROM_ADDR, c); }

String getQueryParam(const String& q, const String& k){
  String pat=k+"="; int i=q.indexOf(pat); if(i<0) return "";
  int j=q.indexOf('&', i+pat.length()); if(j<0) j=q.length();
  String v=q.substring(i+pat.length(), j); v.replace("+"," "); return v;
}
bool parseIp(const String &s, uint8_t out[4]){
  int p1=s.indexOf('.'); int p2=s.indexOf('.',p1+1); int p3=s.indexOf('.',p2+1);
  if(p1<0||p2<0||p3<0) return false;
  long a=s.substring(0,p1).toInt(), b=s.substring(p1+1,p2).toInt();
  long c=s.substring(p2+1,p3).toInt(), d=s.substring(p3+1).toInt();
  if(a<0||a>255||b<0||b>255||c<0||c>255||d<0||d>255) return false;
  out[0]=a; out[1]=b; out[2]=c; out[3]=d; return true;
}
int hexVal(char c){
  if(c>='0'&&c<='9') return c-'0';
  c|=0x20; if(c>='a'&&c<='f') return 10+(c-'a'); return -1;
}
bool parseMac(const String& s, uint8_t out[6]){
  int n=0; int hi=-1,lo=-1; int i=0,len=s.length();
  while(i<len && n<6){
    while(i<len && (s[i]==':'||s[i]=='-'||s[i]==' ')) i++;
    if(i>=len) break;
    if(i<len){ hi=hexVal(s[i++]); } else return false;
    if(i<len){ lo=hexVal(s[i++]); } else return false;
    if(hi<0||lo<0) return false;
    out[n++] = (uint8_t)((hi<<4)|lo);
  }
  return n==6;
}

static inline String humanKB(unsigned long long bytes) {
  unsigned long kb = (unsigned long)((bytes + 1023ULL) / 1024ULL);
  char buf[32];
  snprintf(buf, sizeof(buf), "%lu KB", kb);
  return String(buf);
}

bool resolveHostname(const char* host, IPAddress& outIP) {
  IPAddress dnsIP = Ethernet.dnsServerIP();
  if (dnsIP == IPAddress(0,0,0,0)) {
    dnsIP = IPAddress(DEFAULT_DNS[0], DEFAULT_DNS[1], DEFAULT_DNS[2], DEFAULT_DNS[3]);
  }
  DNSClient dns; dns.begin(dnsIP);
  int rc = dns.getHostByName(host, outIP);
  #if SERIAL_VERBOSE
    Serial.print(F("[NET] DNS ")); Serial.print(ipToString(dnsIP));
    Serial.print(F(" resolver '")); Serial.print(host);
    Serial.print(F("' -> rc=")); Serial.println(rc);
  #endif
  return (rc == 1);
}

// ======== SD Capacidade ========
bool getSdCapacityAndFree(uint64_t &totalBytes, uint64_t &freeBytes) {
  if (!sdAvailable) return false;
  digitalWrite(PIN_CS_ETH, HIGH);
  if (!g_sdCard.begin(SdSpiConfig(PIN_CS_SD, DEDICATED_SPI, SD_SCK_MHZ(25)))) {
    digitalWrite(PIN_CS_SD, HIGH);
    return false;
  }
  if (!g_sdVol.begin(&g_sdCard)) {
    digitalWrite(PIN_CS_SD, HIGH);
    return false;
  }
  const uint32_t sectorsPerCluster = g_sdVol.sectorsPerCluster();
  const uint32_t clusterCount      = g_sdVol.clusterCount();
  totalBytes = (uint64_t)clusterCount * (uint64_t)sectorsPerCluster * 512ULL;
  const uint32_t freeClusters = g_sdVol.freeClusterCount();
  freeBytes = (uint64_t)freeClusters * (uint64_t)sectorsPerCluster * 512ULL;
  digitalWrite(PIN_CS_SD, HIGH);
  return true;
}

// ======== Tempo ========
unsigned long getEpochUTC(){
  if (epochAtLastSync == 0) return 0UL;
  unsigned long secs = (millis() - msAtLastSync)/1000UL;
  return epochAtLastSync + secs;
}

void sendNTPpacket(IPAddress& address) {
  const int NTP_PACKET_SIZE = 48;
  byte packetBuffer[NTP_PACKET_SIZE];
  memset(packetBuffer, 0, NTP_PACKET_SIZE);
  packetBuffer[0] = 0b11100011;
  Udp.beginPacket(address, 123);
  Udp.write(packetBuffer, NTP_PACKET_SIZE);
  Udp.endPacket();
}

void ntpSyncNow(){
  IPAddress timeServerIP(0,0,0,0);
  if (!resolveHostname(NTP_SERVER, timeServerIP)) {
    #if SERIAL_VERBOSE
      Serial.println(F("[NTP] Falha no DNS para servidor NTP (usando DNS fallback)."));
    #endif
  }
  if (timeServerIP != IPAddress(0,0,0,0)) {
    #if SERIAL_VERBOSE
      Serial.print(F("[NTP] Enviando req p/ ")); Serial.println(ipToString(timeServerIP));
    #endif
    sendNTPpacket(timeServerIP);
    delay(800);
    int size = Udp.parsePacket();
    if (size >= 48) {
      byte buf[48];
      Udp.read(buf, 48);
      unsigned long secsSince1900 = (unsigned long)buf[40] << 24 |
                                    (unsigned long)buf[41] << 16 |
                                    (unsigned long)buf[42] << 8  |
                                    (unsigned long)buf[43];
      const unsigned long seventyYears = 2208988800UL;
      unsigned long epochUTC = secsSince1900 - seventyYears;
      epochAtLastSync = epochUTC;
      msAtLastSync    = millis();
      #if SERIAL_VERBOSE
        Serial.print(F("[NTP] Sync OK. epoch=")); Serial.println(epochUTC);
      #endif
    } else {
      #if SERIAL_VERBOSE
        Serial.println(F("[NTP] Resposta inválida / timeout."));
      #endif
    }
  } else {
    #if SERIAL_VERBOSE
      Serial.println(F("[NTP] IP do servidor NTP não resolvido."));
    #endif
  }
  lastNtpSyncMs = millis();
}

uint32_t currentYYYYMM(unsigned long epochUTC){
  if (epochUTC == 0) return 0UL;
  unsigned long days = epochUTC / 86400UL;
  int y = 1970; unsigned long d = days;
  while (true) {
    bool leap = (y%4==0 && (y%100!=0 || y%400==0));
    unsigned long diy = leap ? 366 : 365;
    if (d >= diy) { d -= diy; y++; } else break;
  }
  int md[12] = {31,28,31,30,31,30,31,31,30,31,30,31};
  bool leap = (y%4==0 && (y%100!=0 || y%400==0));
  if (leap) md[1] = 29;
  int m = 0;
  while (m<12 && d >= (unsigned long)md[m]) { d -= md[m]; m++; }
  return (uint32_t)y*100UL + (uint32_t)(m+1);
}

static inline void formatMonthFilenameFromYM(uint16_t year, uint8_t month, char* out, size_t sz) {
  if (month < 1)  month = 1;
  if (month > 12) month = 12;
  snprintf(out, sz, "L%04u%02u.CSV", (unsigned)year, (unsigned)month);
}
static inline void formatMonthFilenameFromYYYYMM(uint32_t yyyymm, char* out, size_t sz) {
  uint16_t year  = (uint16_t)(yyyymm / 100U);
  uint8_t  month = (uint8_t)(yyyymm % 100U);
  formatMonthFilenameFromYM(year, month, out, sz);
}

bool updateMonthFileName(unsigned long epochUTC){
  if (epochUTC == 0) return false;
  unsigned long days = epochUTC / 86400UL;
  int y = 1970; unsigned long d = days;
  while (true) {
    bool leap = (y%4==0 && (y%100!=0 || y%400==0));
    unsigned long diy = leap ? 366 : 365;
    if (d >= diy) { d -= diy; y++; } else break;
  }
  int md[12] = {31,28,31,30,31,30,31,31,30,31,30,31};
  bool leap = (y%4==0 && (y%100!=0 || y%400==0));
  if (leap) md[1]=29;
  int m=0; while (m<12 && d >= (unsigned long)md[m]) { d -= md[m]; m++; }
  snprintf(currentMonthFile, sizeof(currentMonthFile), "L%04d%02d.CSV", y, m+1);
  return true;
}

// ======== LCD ========
void printIPToSerial(){
  Serial.print(F("[NET] IP: ")); Serial.print(Ethernet.localIP());
  Serial.print(F(" | GW: ")); Serial.print(Ethernet.gatewayIP());
  Serial.print(F(" | DNS: ")); Serial.print(Ethernet.dnsServerIP());
  Serial.print(F(" | Mask: ")); Serial.println(Ethernet.subnetMask());
  Serial.println(F("[HTTP] Servidor na porta 80"));
}
void printIPLine(){
  IPAddress ip = Ethernet.localIP();
  char line[17];
  snprintf(line,sizeof(line),"%u.%u.%u.%u",ip[0],ip[1],ip[2],ip[3]);
  lcd.setCursor(0,0); lcd.print("                ");
  lcd.setCursor(0,0); lcd.print(line);
}
void printTHLine(){
  char line[17]; char tbuf[8], hbuf[8];
  dtostrf(lastTemp,4,1,tbuf); dtostrf(lastHum,4,1,hbuf);
  snprintf(line,sizeof(line),"T:%sC H:%s%%",tbuf,hbuf);
  lcd.setCursor(0,1); lcd.print("                ");
  lcd.setCursor(0,1); lcd.print(line);
}

// ======== Buzzer ========
void beep(uint16_t f,uint16_t ms){ tone(PIN_BUZZER,f,ms); delay(ms+5); noTone(PIN_BUZZER); }
void startupChime(){ beep(1200,120); beep(1600,120); beep(2000,160); }

// ======== SD ========
void sdInit(){
  digitalWrite(PIN_CS_ETH, HIGH);
  sdAvailable = SD.begin(PIN_CS_SD);
  #if SERIAL_VERBOSE
    if (!sdAvailable) Serial.println(F("[SD ] Nao detectado. Historico DESATIVADO."));
    else              Serial.println(F("[SD ] OK. Historico ATIVADO."));
  #endif
}

bool sdAppendLog(float t, float h) {
  if (!sdAvailable) return false;
  if (sdBusy) {
    #if SERIAL_VERBOSE
      Serial.println(F("[SD ] Ignorado append: SD ocupado."));
    #endif
    return false;
  }
  sdBusy = true;

  bool firstLog = isnan(lastLoggedTemp) || isnan(lastLoggedHum);
  bool dt = !firstLog && (fabsf(t - lastLoggedTemp) >= 1.0f);
  bool dh = !firstLog && (fabsf(h - lastLoggedHum ) >= 1.0f);
  if (!firstLog && !dt && !dh) {
    sdBusy=false;
    #if SERIAL_VERBOSE
      Serial.println(F("[LOG] Mudanca < 1.0 -> nao grava."));
    #endif
    return false;
  }

  unsigned long epoch = getEpochUTC();
  if (epoch == 0) {
    sdBusy=false;
    #if SERIAL_VERBOSE
      Serial.println(F("[LOG] Sem epoch (NTP) -> nao grava."));
    #endif
    return false;
  }

  digitalWrite(PIN_CS_ETH, HIGH);

  if (!updateMonthFileName(epoch)) { sdBusy=false; return false; }
  char fname[20];
  strncpy(fname, currentMonthFile, sizeof(fname));
  fname[sizeof(fname)-1] = '\0';

  bool newFile = !SD.exists(fname);
  File f = SD.open(fname, FILE_WRITE);
  if (!f) {
    Serial.print(F("[SD ] Falha ao abrir ")); Serial.println(fname);
    digitalWrite(PIN_CS_SD, HIGH);
    sdBusy=false;
    return false;
  }

  if (newFile) f.println(F("epoch,temperature,humidity"));
  f.print(epoch); f.print(','); f.print(t, 2); f.print(','); f.println(h, 2);
  f.flush();
  f.close();

  lastLoggedTemp = t;
  lastLoggedHum  = h;

  digitalWrite(PIN_CS_SD, HIGH);
  sdBusy = false;

  #if SERIAL_VERBOSE
    Serial.print(F("[LOG] + ")); Serial.print(fname);
    Serial.print(F(" -> ")); Serial.print(t,2);
    Serial.print(F("C, ")); Serial.print(h,2);
    Serial.println(F("%"));
  #endif
  return true;
}

// ======== HTTP util ========
void sendHtmlHeader(EthernetClient &c){
  c.println(F("HTTP/1.1 200 OK"));
  c.println(F("Content-Type: text/html; charset=utf-8"));
  c.println(F("Connection: close"));
  c.println();
}
void sendJsonHeader(EthernetClient &c){
  c.println(F("HTTP/1.1 200 OK"));
  c.println(F("Content-Type: application/json; charset=utf-8"));
  c.println(F("Access-Control-Allow-Origin: *"));
  c.println(F("Connection: close"));
  c.println();
}
void sendNotFound(EthernetClient &c){
  c.println(F("HTTP/1.1 404 Not Found"));
  c.println(F("Content-Type: text/plain; charset=utf-8"));
  c.println(F("Connection: close"));
  c.println(); c.println(F("404"));
}

// --- humanSize / printSdStatusHtml ---
String humanSize(unsigned long long bytes) {
  char buf[32];
  if (bytes < 1024ULL) { snprintf(buf, sizeof(buf), "%llu B", bytes); return String(buf); }
  double kb = bytes / 1024.0;
  if (kb < 1024.0)     { snprintf(buf, sizeof(buf), "%.1f KB", kb); return String(buf); }
  double mb = kb / 1024.0;
  if (mb < 1024.0)     { snprintf(buf, sizeof(buf), "%.1f MB", mb); return String(buf); }
  double gb = mb / 1024.0;
  snprintf(buf, sizeof(buf), "%.2f GB", gb);
  return String(buf);
}
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
void loop(){
  // splash
  if(!ipSplashDone && (millis()-ipSplashStartMs>=IP_SPLASH_MS)){
    ipSplashDone=true; printIPLine();
    if(!isnan(lastTemp) && !isnan(lastHum)) printTHLine();
    else { lcd.setCursor(0,1); lcd.print("Aguardando DHT "); }
  }

  // NTP re-sync
  if (millis() - lastNtpSyncMs > NTP_INTERVAL_MS) {
    Serial.println(F("[NTP] Re-sincronizando..."));
    ntpSyncNow();
  }

  // DHCP lease maintain (apenas em DHCP)
  if (!cfg.use_static) {
    int rc = Ethernet.maintain(); // 1-renew fail, 2-renew OK, 3-rebind fail, 4-rebind OK
    if (rc == 1) Serial.println(F("[NET] DHCP renew FAIL"));
    else if (rc == 2) { Serial.println(F("[NET] DHCP renew OK")); printIPToSerial(); }
    else if (rc == 3) Serial.println(F("[NET] DHCP rebind FAIL"));
    else if (rc == 4) { Serial.println(F("[NET] DHCP rebind OK")); printIPToSerial(); }
  }

  sampleSensorIfNeeded();

  // HTTP
  EthernetClient client = server.available();
  if(client){ handleHttp(client); delay(1); client.stop(); }
}

// Retorna YYYYMM atual (via NTP) ou mais recente no SD (fallback).
uint32_t getCurrentOrLatestYYYYMM() {
  uint32_t yyyymm = currentYYYYMM(getEpochUTC());
  if (yyyymm != 0UL) return yyyymm;
  if (!sdAvailable) return 0UL;
  digitalWrite(PIN_CS_ETH, HIGH);
  File root = SD.open("/");
  uint32_t best = 0;
  if (root) {
    File entry = root.openNextFile();
    while (entry) {
      if (!entry.isDirectory()) {
        char nm[32] = {0};
        entry.getName(nm, sizeof(nm));
        size_t len = strlen(nm);
        if (len == 11 && nm[0] == 'L' && nm[7] == '.' && nm[8] == 'C' && nm[9] == 'S' && nm[10] == 'V') {
          bool ok = true;
          for (int i = 1; i <= 6; i++) if (nm[i] < '0' || nm[i] > '9') ok = false;
          if (ok) {
            char buf[7]; memcpy(buf, nm + 1, 6); buf[6] = '\0';
            uint32_t val = (uint32_t)atoi(buf);
            if (val > best) best = val;
          }
        }
      }
      entry.close();
      entry = root.openNextFile();
    }
    root.close();
  }
  digitalWrite(PIN_CS_SD, HIGH);
  return best;
}

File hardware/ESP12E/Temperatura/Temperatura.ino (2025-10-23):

/*******************************************************
 * ESP8266 - DHT22 + HTTP + Config + Calib + Média(10)
 * Wi-Fi:
 *   Tipo 1 = PSK (DEFAULT: SSID=maurinsrv / PASS=1425361425)
 *   Tipo 2 = WPA2-Enterprise (PEAP/MSCHAPv2)
 *            • Outer Identity (FIXO): anonymous@coderp.sp.gov.br
 *            • Inner Username/Password: via /config, persistidos em EEPROM
 *
 * Recursos:
 *   - EEPROM persistente (credenciais, calibração, MAC custom)
 *   - Fallback: 3 falhas ⇒ DEFAULT_SSID/DEFAULT_PASS (Tipo 1)
 *   - /ws/state (pipeline EAP + motivo de desconexão)
 *   - /ws/coleta (status, leituras, fw, etc.)
 *   - /dht (JSON compatível com campos antigos/atuais)
 *   - /mac (alterar MAC persistente)
 *   - /calib (coeficientes, auto-calibração)
 *   - Versão do firmware nos JSONs e Serial
 *******************************************************/

#include <ESP8266WiFi.h>
#include <ESP8266WebServer.h>
#include <EEPROM.h>
#include <DHT.h>

extern "C" {
  #include "user_interface.h"
  #include "wpa2_enterprise.h"   // WPA2-Enterprise (ESP8266 core)
}

ESP8266WebServer server(80);

// === Blynk ===
#define BLYNK_TEMPLATE_ID   "TMPL2lEGiwwEI"
#define BLYNK_TEMPLATE_NAME "Quickstart Template"
#define BLYNK_AUTH_TOKEN    "EcDFkG_nACLP34JdV9hs-yLbHRPimLFi"  // use o seu

#define BLYNK_PRINT Serial
#include <BlynkSimpleEsp8266.h>
#include <Blynk/BlynkTimer.h>  // temporizador do Blynk
//#include <BlynkTimer.h>



// ====== Firmware ======
#define FW_NAME     "ESP8266-TempHum"
#define FW_VERSION  "3.0.0"
#define FW_BUILD    (__DATE__ " " __TIME__)

// ====== Defaults/Fallback ======
#define DEFAULT_SSID "maurinsrv"
#define DEFAULT_PASS "1425361425"

// ====== DHT ======
#define DHTPIN   4
#define DHTTYPE  DHT22
DHT dht(DHTPIN, DHTTYPE);

// ====== EEPROM Layout ======
#define EEPROM_SIZE 512
static const uint32_t WIFI_MAGIC_V3 = 0x42A1C0E3;
static const uint32_t CAL_MAGIC     = 0xC0A1B123;

BlynkTimer blynkTimer;
bool g_blynkReady = false;       // já fiz config()?
bool g_blynkConnected = false;   // status de conexão ao cloud


struct WifiStoreV3 {
  uint32_t magic;
  uint8_t  auth_type;              // 1=PSK, 2=EAP
  char ssid[33];
  char pass[65];
  char eap_identity[65];           // legado (ignorado em runtime; usamos outer fixo)
  char eap_username[65];           // INNER
  char eap_password[65];           // INNER
  uint8_t mac_custom;
  uint8_t mac[6];
};

struct CalibStore {
  uint32_t magic;
  float temp_gain, temp_offset;
  float hum_gain,  hum_offset;
};

const size_t WIFI_ADDR = 0;
const size_t CAL_ADDR  = sizeof(WifiStoreV3);

// ====== EAP (Outer Identity FIXO) ======
static const char* EAP_OUTER_IDENTITY_FIXED = "anonymous@coderp.sp.gov.br";

// ====== CA do RADIUS (COLE O PEM AQUI) ======
static const char CA_PEM_CODERP_8266[] PROGMEM = R"PEM(-----BEGIN CERTIFICATE-----
PASTE_YOUR_CODERP_CA_PEM_HERE
-----END CERTIFICATE-----
)PEM";

// ====== Estado runtime ======
enum WifiConnState { WIFI_IDLE, WIFI_CONNECTING, WIFI_CONNECTED, WIFI_BACKOFF };

static const uint32_t WIFI_FIRST_TIMEOUT_MS   = 8000;
static const uint32_t WIFI_MAX_TIMEOUT_MS     = 20000;
static const uint32_t WIFI_RETRY_COOLDOWN_MS  = 15000;

#define LED_ON()  digitalWrite(LED_BUILTIN, LOW)
#define LED_OFF() digitalWrite(LED_BUILTIN, HIGH)
#define LED_TG()  digitalWrite(LED_BUILTIN, !digitalRead(LED_BUILTIN))

WifiConnState wifiConnState = WIFI_IDLE;
uint32_t connectStartedAt=0, nextRetryAt=0, connectTimeoutMs=WIFI_FIRST_TIMEOUT_MS;
uint8_t  failCount=0;
bool     usingDefault=false;

struct WifiRuntime {
  uint8_t  auth_type; // 1,2
  String   ssid, pass;
  String   eap_identity, eap_username, eap_password;
  bool     mac_custom; uint8_t mac[6];
} g_cfg;

String g_active_ssid;

WiFiEventHandler g_onDisc;
volatile uint8_t g_lastDiscReason=0;

// ====== EAP (Enterprise) — pipeline de estágios para LOG ======
enum EapStage : uint8_t {
  EAP_IDLE=0, EAP_INIT, EAP_SET_SSID, EAP_SET_CA, EAP_SET_IDENTITY, EAP_SET_USERNAME,
  EAP_SET_PASSWORD, EAP_ENABLE, EAP_CONNECT, EAP_SUCCESS, EAP_ERROR
};



volatile EapStage g_eapStage = EAP_IDLE;
String g_eapMsg;

// ====== LOG CODERP ======
static inline void coderpLog(const char* stage, const String& msg) {
  Serial.printf("[CODERP] %-12s | %8lu ms | SSID='%s' | %s\n",
    stage, millis(), g_active_ssid.c_str(), msg.c_str());
}
static String caPreview(const char* pem) {
  if(!pem || !*pem) return String("CA: (vazia)");
  String body = String(pem).substring(0, 60);
  body.replace("\n","\\n");
  return String("CA preview: \"") + body + "\" ...";
}
static void setEapStage(EapStage st, const String& msg){
  g_eapStage = st; g_eapMsg = msg;
  const char* name =
    (st==EAP_IDLE?"IDLE":st==EAP_INIT?"INIT":st==EAP_SET_SSID?"SET_SSID":
     st==EAP_SET_CA?"SET_CA":st==EAP_SET_IDENTITY?"IDENTITY":st==EAP_SET_USERNAME?"USERNAME":
     st==EAP_SET_PASSWORD?"PASSWORD":st==EAP_ENABLE?"ENABLE":st==EAP_CONNECT?"CONNECT":
     st==EAP_SUCCESS?"SUCCESS":"ERROR");
  Serial.printf("[EAP] %02u %-12s | %lu ms | %s\n", (unsigned)st, name, millis(), msg.c_str());
}

// ====== Calibração + Média ======
float TEMP_GAIN=1.0f, TEMP_OFFSET=0.0f, HUM_GAIN=1.0f, HUM_OFFSET=0.0f;

struct DhtReading { float t,h; bool ok; float t_raw,h_raw; float t_avg,h_avg; uint8_t n_avg; };
DhtReading lastDht={NAN,NAN,false,NAN,NAN,NAN,NAN,0};
static const uint8_t AVG_WIN=10; float bufT[AVG_WIN], bufH[AVG_WIN];
uint8_t bufCount=0, bufPos=0; double sumT=0.0, sumH=0.0;

// ====== Utils ======
inline void safeYield(){ delay(0); }
inline void avgReset(){ bufCount=0; bufPos=0; sumT=sumH=0; lastDht.t_avg=lastDht.h_avg=NAN; lastDht.n_avg=0; }
inline void avgAddSample(float t,float h){
  if(bufCount<AVG_WIN){ bufT[bufCount]=t; bufH[bufCount]=h; sumT+=t; sumH+=h; bufCount++; }
  else { sumT-=bufT[bufPos]; sumH-=bufH[bufPos]; bufT[bufPos]=t; bufH[bufPos]=h; sumT+=t; sumH+=h; bufPos=(bufPos+1)%AVG_WIN; }
  lastDht.t_avg=float(sumT/bufCount); lastDht.h_avg=float(sumH/bufCount); lastDht.n_avg=bufCount;
}
static inline float clampf(float v,float lo,float hi){ if(isnan(v))return v; if(v<lo)return lo; if(v>hi)return hi; return v; }
static String argOrEmpty(const String& k){ return server.hasArg(k)? server.arg(k) : String(""); }

// ====== Info Wi-Fi ======
const char* phyToStr(WiFiPhyMode_t m){
  switch(m){ case WIFI_PHY_MODE_11B: return "802.11b";
             case WIFI_PHY_MODE_11G: return "802.11g";
             case WIFI_PHY_MODE_11N: return "802.11n";
             default: return "unknown"; }
}
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
